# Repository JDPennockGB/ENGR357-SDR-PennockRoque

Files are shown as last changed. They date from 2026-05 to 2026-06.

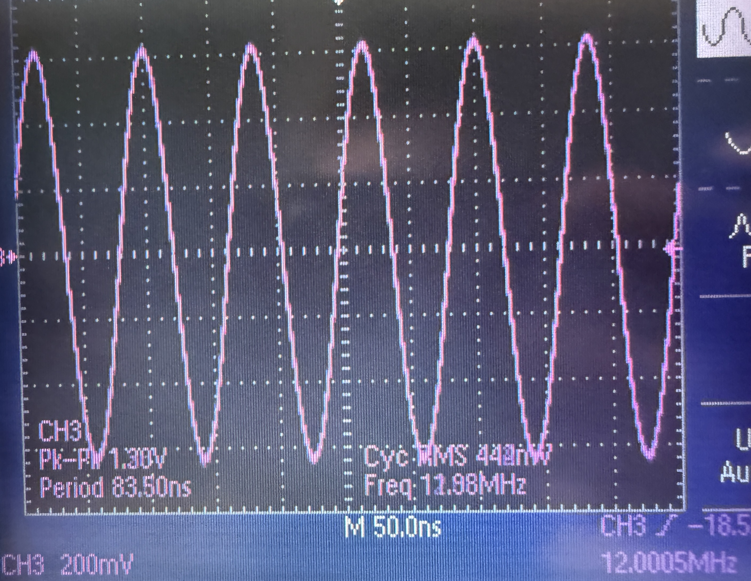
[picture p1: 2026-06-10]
Images/PicoClock.JPG

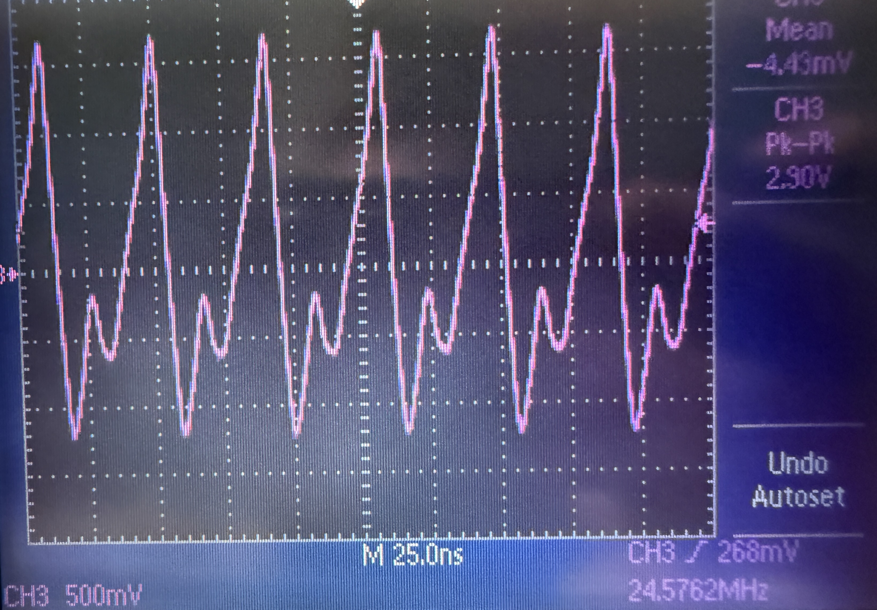
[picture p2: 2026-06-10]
Images/CmosClock.JPG

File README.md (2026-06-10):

# ENGR 357 Pico SDR Receiver

A custom-built, high-performance Software Defined Radio (SDR) receiver powered by the Raspberry Pi Pico (RP2040). This project combines a classic hardware Tayloe detector with modern digital signal processing, streaming 24-bit I/Q audio and CAT control over a single USB cable directly to PC-based SDR software like **Quisk**.

GitHub Link: https://github.com/JDPennockGB/ENGR357-SDR-PennockRoque 

---

## Overview

Traditional homebrew SDR receivers often rely on routing analog audio cables into a PC soundcard, which can introduce noise and ground loops. This project solves that by digitizing the baseband I/Q signals directly on the board using a dedicated 24-bit ADC, and utilizing the RP2040's hardware PIO and TinyUSB stack to act as a **Composite CDC-UAC1 USB Device**. 

When plugged into a computer, this radio appears simultaneously as:
1. **USB Audio Class 2.0 (UAC2) Input:** Streaming ultra-clean 24-bit stereo I/Q audio to the PC.
2. **USB CDC Serial Port:** Receiving standard CAT tuning commands from the SDR software.

## Key Features

ADD FEATURES

---

## Hardware
### Overview
* **MCU:** Raspberry Pi Pico (RP2040) utilizing PIO and DMA for zero-jitter data handling.
* **Clock Generator:** Si5351A providing precise LO generation and the 12.288 MHz Master Clock (MCLK) for the ADC.
* **Quadrature Generator:** SN74AC74 Johnson counter for exact 90-degree I/Q phase shifting.
* **Mixer (Tayloe Detector):** SN74CBT3253 Quadrature Sampling Detector.
* **Baseband Amplification:** OPA2350 high-speed, low-noise operational amplifiers.
* **Digitization:** PCM1808 24-bit Stereo I2S ADC.
* **User Interface:** * Newhaven 1x8 Character LCD (ST7066U / 3.3V)
  * Quadrature Rotary Encoder with push-button for VFO tuning
  * 4x SMD Push Buttons for menu/mode navigation (not currently implemented in software)

### Pinout Configuration
The following table outlines the physical connections between the Raspberry Pi Pico and your hardware components.

| Pin | Function | Connected | Implemented |
| :--- | :--- | :---: | :---: |
| **GPIO0** | BCK | ✅ | ❌ |
| **GPIO1** | WS | ✅ | ❌ |
| **GPIO2** | DOUT | ✅ | ❌ |
| **GPIO11** | SD | ✅ | ❌ |
| **GPIO3** | LCD_Bit0 | ✅ | ✅ |
| **GPIO4** | LCD_Bit1 | ✅ | ✅ |
| **GPIO5** | LCD_Bit2 | ✅ | ✅ |
| **GPIO6** | LCD_Bit3 | ✅ | ✅ |
| **GPIO7** | LCD_Bit4 | ✅ | ✅ |
| **GPIO8** | LCD_Bit5 | ✅ | ✅ |
| **GPIO9** | LCD_Bit6 | ✅ | ✅ |
| **GPIO10** | LCD_Bit7 | ✅ | ✅ |
| **GPIO12** | I2C Bus SDA | ✅ | ✅ |
| **GPIO13** | I2C Bus SCL | ✅ | ✅ |
| **GPIO14** | LCD_RegSel | ✅ | ✅ |
| **GPIO15** | LCD_Ena | ✅ | ✅ |
| **GPIO16** | Up_Btn | ✅ | ❌ |
| **GPIO17** | Left_Btn | ✅ | ❌ |
| **GPIO18** | Select_Btn | ✅ | ❌ |
| **GPIO19** | Right_Btn | ✅ | ❌ |
| **GPIO20** | Encoder_A | ✅ | ✅ |
| **GPIO21** | Encoder_B | ✅ | ✅ |
| **GPIO22** | Encoder_Button| ✅ | ❌ |
| **GPIO26** | ADC0 (I_OUT) | ❌ | ❌ |
| **GPIO27** | ADC1 (Q_OUT) | ❌ | ❌ |
| **AGND** | GND | ✅ | ✅ |
| **VBUS** | +5v Bus | ✅ | ✅ |
| **3v3** | +3.3v Bus | ✅ | ✅ |

---

## Software
### Overview
* **Framework:** C/C++ via the Raspberry Pi Pico SDK.
* **USB Stack:** TinyUSB configured for a unidirectional composite UAC1 Capture + CDC interface.
* **DSP Pipeline:** Custom PIO state machines reading I2S data, fed via DMA directly to USB buffers without bottlenecking the CPU.

### Function Reference

#### LCD Driver (`lcd_driver.c`)
Manages the 8-bit parallel interface for the ST7066U controller.

| Function | Description |
| :--- | :--- |
| `void lcd_init()` | [cite_start]Executes the power-on initialization routine, including the 3-step "Wake up" sequence required for the ST7066U controller to stabilize[cite: 259]. |
| `void lcd_command(uint8_t cmd)` | Sets the `RS` (Register Select) pin LOW for command mode, drives the 8-bit bus, and toggles the `E` (Enable) pin to latch data. |
| `void lcd_clear()` | [cite_start]Sends the `0x01` instruction to clear the display RAM and reset the cursor[cite: 178]. |
| `void lcd_print(const char* str)` | Sets `RS` HIGH for data mode, iterates through the string, and writes character bytes to the LCD data bus. |

#### Clock Synthesizer (`si5351.c`)
Interfaces with the Si5351 via I2C for frequency generation.

| Function | Description |
| :--- | :--- |
| `bool si5351_init(i2c_inst_t *i2c)` | [cite_start]Initializes I2C, verifies device status, and loads factory crystal load settings[cite: 172]. |
| `uint32_t si5351_set_frequency(...)` | Calculates PLL and MultiSynth divisors, programs the register blocks, resets the PLL to achieve frequency lock, and enables the output clock. |

#### Command & Control (`cdc_app.c` & `main.c`)
Handles communication and system state.

| Function | Description |
| :--- | :--- |
| `void cdc_task()` | Parses incoming serial data for Quisk-compatible commands (e.g., `FREQ`, `VER`, `XTAL`), enabling remote control of the SDR. |
| `static void process_command(const char *line)` | Dispatcher function that maps string commands (like `FREQ`) to specific hardware actions. |
| `void audio_task()` | Handles the audio buffer from the DMA/FIFO into the USB streaming interface. |
| `void encoder_callback(...)` | ISR that tracks encoder rotation to update the `current_hz` variable, which is then processed by the main loop. |

### Build Instructions
1. **Prerequisites**: Ensure the `Pico SDK` abd `TinyUSB` libraries are installed
2. **Setup**:
   ```bash
   cd /path/to/sdr-firmware
   rm -rf build && mkdir build && cd build

---

## Repository Structure

This repository contains the hardware design files, the C/C++ firmware, Python unit tests, and relevant research documentation.

ENGR-357-SDR/

├── Documents/              # Research notes, datasheets, and design requirements

├── KiCad Designs/          # PCB schematics, layout files, and BOMs

│   ├── v1 Switch Mixer/

│   ├── v2 Tayloe Detector/

│   └── v3 Tayloe Detector FINAL/

├── LT Spice Simulations/   # RF demodulator analysis and circuit models

│   ├── LTSpice project files/

│   └── Simulation Results/ # Images of simulation results

└── sdr-firmware/           # RP2040 Firmware (Pico SDK)

    ├── build/              # Compiled binaries and artifacts

    ├── PythonUnitTests/    # Verification and testing scripts

    └── main.c + drivers                # C firmware source files

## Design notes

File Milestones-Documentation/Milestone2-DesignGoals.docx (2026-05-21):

Milestone #2

SDR Design Goals and reasoning:

- Simplicity and reliability
- Low cost and accessibility of components
- Educational demonstrating both analog and digital signal processing

The goal of this project is to design and implement a software-assisted AM radio receiver capable of receiving and demodulating amplitude modulated (AM) signals in the standard broadcast band. The design combines analog front-end circuits with digital processing using a Raspberry Pico to create a flexible and cost-effective receiver.

Reasoning:

- AM modulation was chosen because it is simpler to implement and easier to demodulate compared to FM or SSB.
- A mixer + clock (local oscillator) is used to shift the signal to a lower frequency for easier processing.
- An ADC allows for conversion of analog signals into digital form, enabling software signal processing.

Specifications:

- Frequency range
  - 535–1705 kHz
- Modulation Type
  - AM (Amplitude Modulation)
- Minimum discernible signal
  - 10 µV
- User Interface
  - Rotary encoder
  - push buttons
  - LCD/OLED
- Processing Hardware
  - Raspberry Pi Pico RP2040 microcontroller
- Audio Output
  - Headphones or speaker
- Size/Weight
  - Handheld (Walkman size plus antenna)
- Power requirements
  - 5V via USB-C
- Software and computer requirements
  - Nice UI, easy to navigate and makes sense
- Special Features:
  - SD/.WAV recording
  - Storage – SD card or direct over USB
- Cost
  - $40 – $50 depending on components

System Architecture Overview

The receiver follows a Direct Conversion (Zero-IF) architecture. The radio frequency is mixed down to baseband (audio) using a high-speed analog switch driven by a programmable clock.

Signal Path & Sub-Circuits

A. The Front-End (Antenna & Filter)

- Antenna
- Protection: Back-to-back 1N4148 diodes to ground to prevent ESD damage.
- Pre-selector: A Passive Band-Pass Filter (BPF) designed for 500 kHz – 1.8 MHz. This prevents "images" from FM or Shortwave bands from entering the mixer.
- Buffer: A single-transistor JFET buffer (e.g., J310) to match the high-impedance antenna to the low-impedance detector.
- Transformer: Feeds into demodulator.

B. The Demodulator

- Switching IC: A high-speed analog demultiplexer.
- Operation: The switch rotates through 2 positions at the target frequency.

C. The Clock Engine (Digital Tuning)

- Clock Gen: Si5351A controlled via I2C by the Pi Pico.
- Frequency Logic: To listen to 1800 kHz, the Si5351 outputs 1800 kHz.

D. Post-Mixer Amplification (The "Bridge")

- Dual Op-Amp: NE5532 or TL072 configured as differential amplifiers.
- Biasing: Signal is biased for compatibility with the Pi Pico ADC.
- Filtering: Active Low-Pass Filter at 10 kHz to remove switching noise.

E. The Output Split

1. Digital Branch: Signal feed into Pico ADC (GP26/27).
2. Analog Branch: Signal passes through a 10µF DC-blocking capacitor -> Audio Potentiometer & Power Amplifier -> Speaker/3.5mm Jack.

3. Control & UI (The Pi Pico)

- Input: Rotary encoder for frequency selection.
- Display: I2C OLED to show the current frequency.
- Software: The Pico runs a loop that calculates the frequency for the Si5351 and can optionally perform an FFT on the ADC data to show a "spectrum" of the AM band.

Block Diagram:

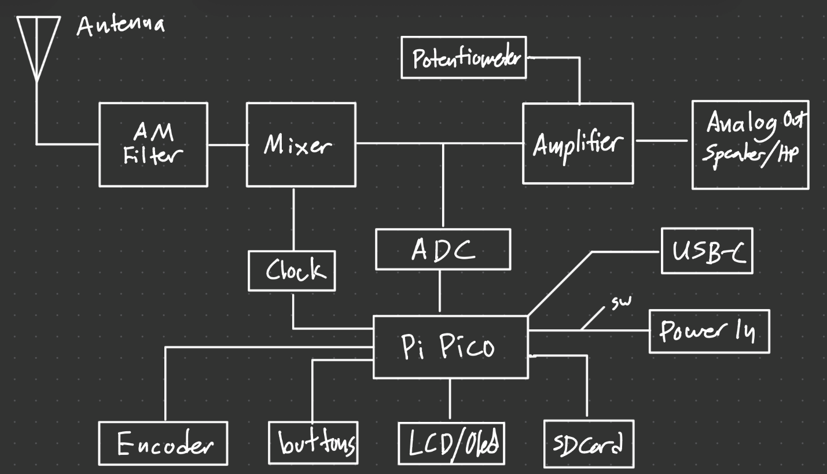
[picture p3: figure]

Explanation:

1. Antenna
  a. Receives electromagnetic AM signals from the air.
2. AM Filter
  a. Filters the incoming signal to isolate the desired frequency range and reduce interference from other signals.
3. Mixer + Clock (Local Oscillator)
  a. Local Oscillator acts like a signal generator, creating new signals. The mixer then combines the signal, lowering the frequency, making the radio process a lower frequency. Lower frequency allows for easier filtering
4. Signal Split Path
  a. One path goes to the ADC
  b. Another goes through an amplifier for audio output
5. ADC
  a. Convert the analog signal into digital samples.
6. Amplifier and Potentiometer
  a. Amplifies audio signal
  b. Potentiometer controls volume
7. Analog Output
  a. Outputs the recovered audio signal thorough speaker or headphones
8. Pi Pico
  a. Processes the sampled signal
  b. Controls display and storage
  c. Can demodulation extracting audio from AM signal
9. User Interface
  a. Encoder: tuning frequency
  b. Buttons: controls modes
  c. LCD/OLED: display frequency, status
10. Power Supply
  a. USB-C 5V
11. SD card
  a. Stores recorded signals or processed data.

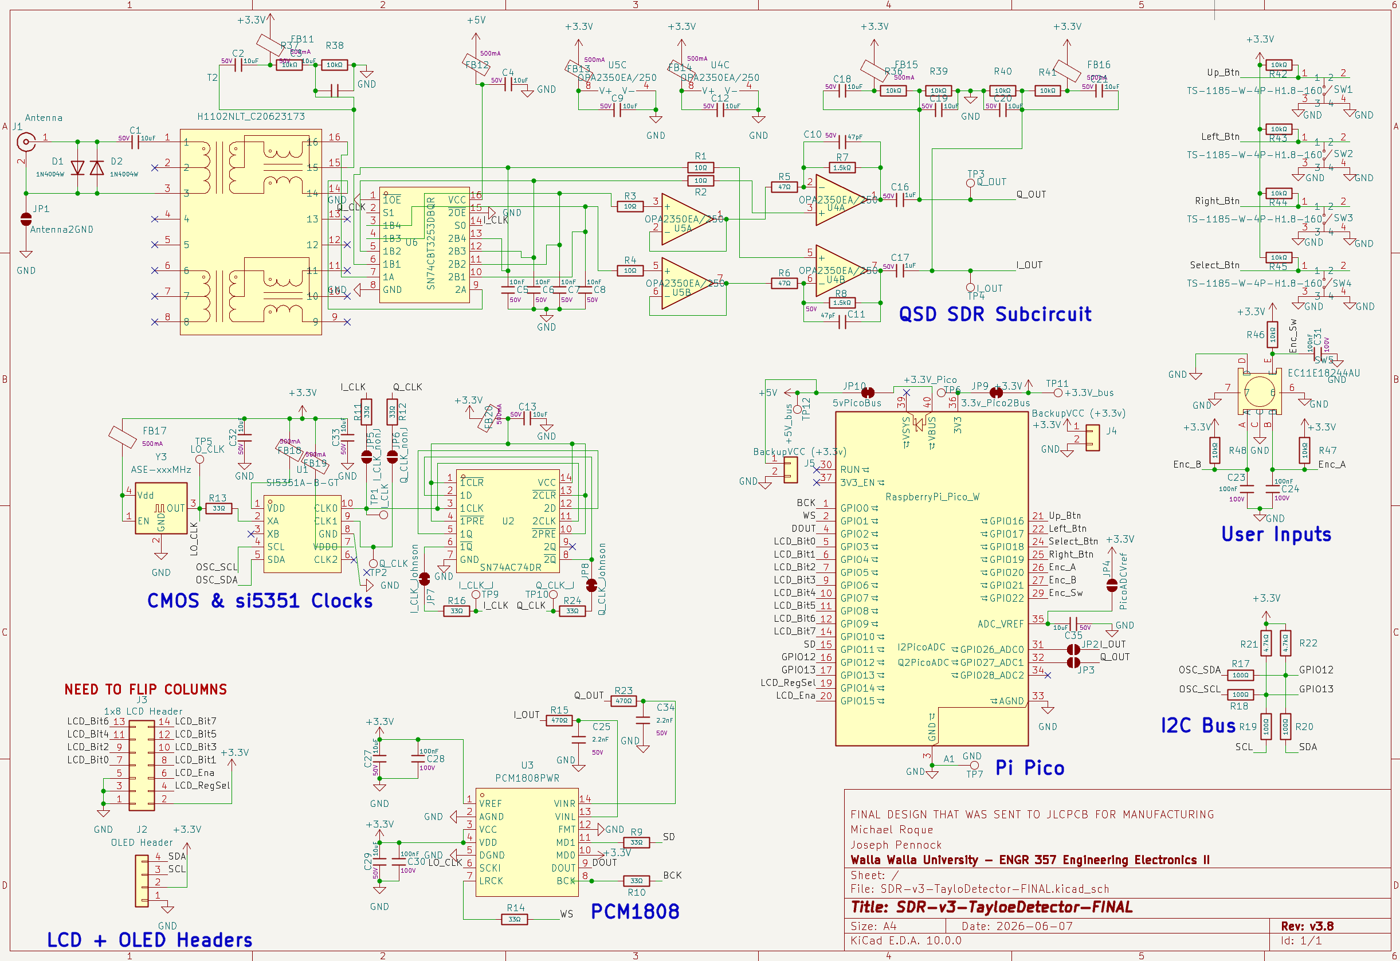
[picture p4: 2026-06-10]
Images/FullSchematic.png

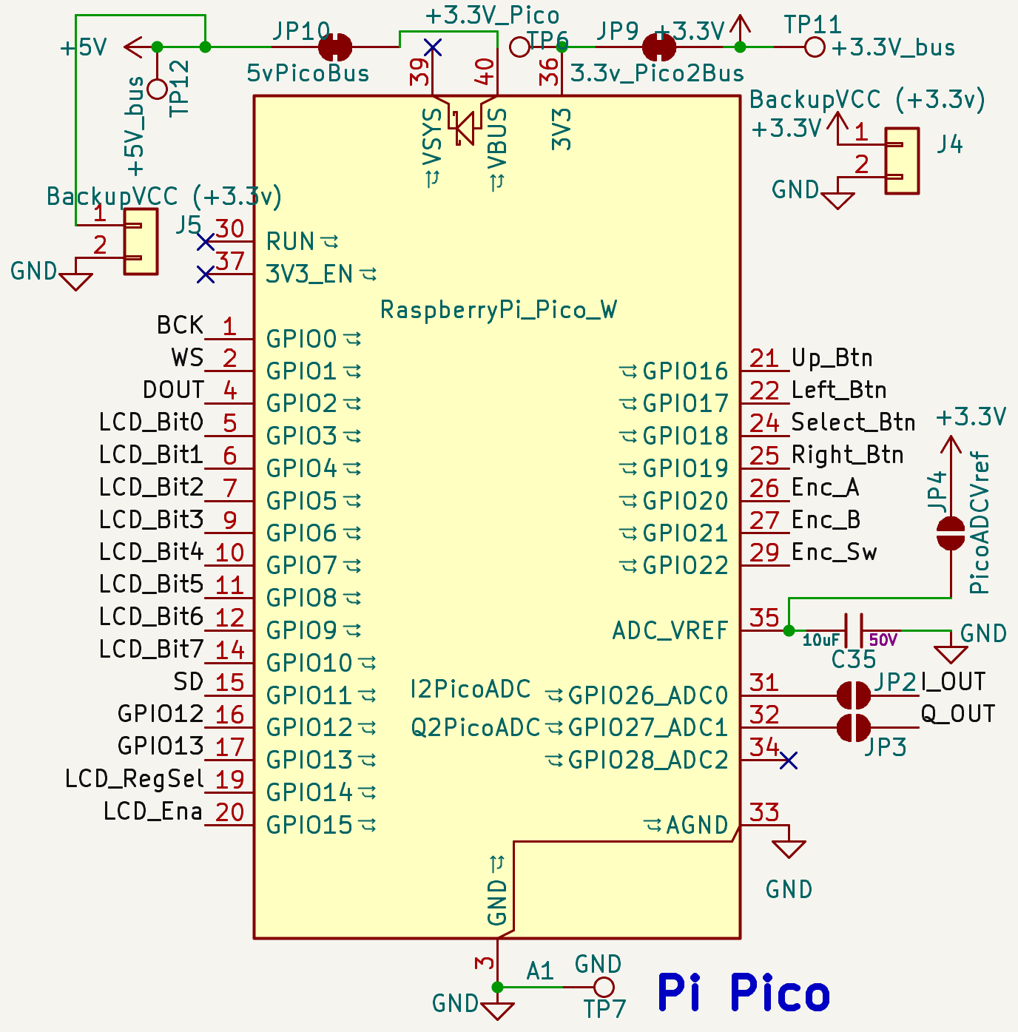
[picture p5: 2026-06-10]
Images/PicoCircuit.png

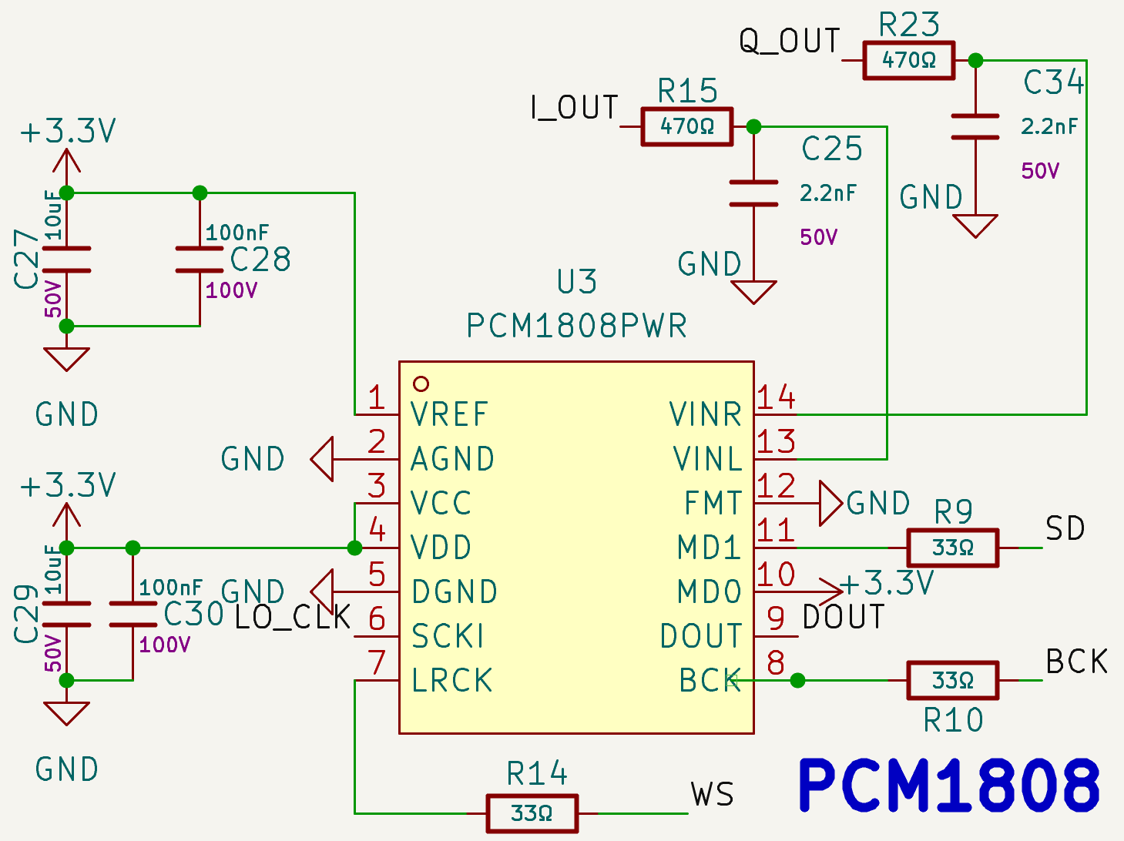
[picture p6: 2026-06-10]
Images/ADCcircuit.png

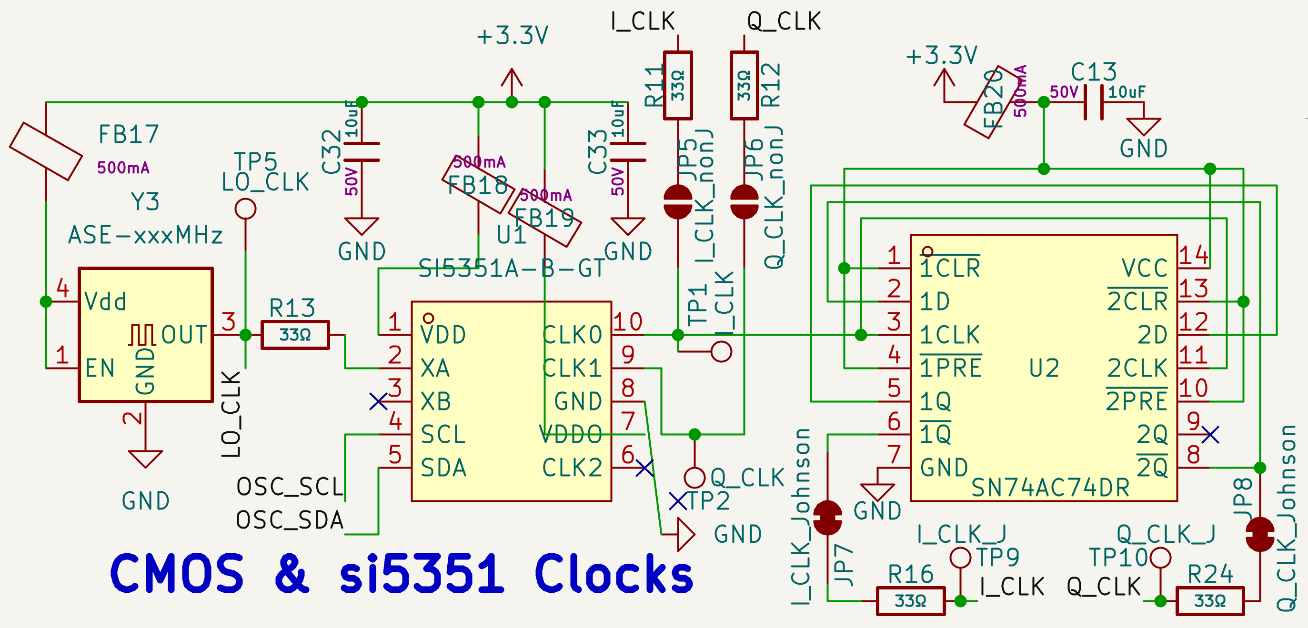
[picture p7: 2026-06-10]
Images/CMOSsi5351Circuit.png

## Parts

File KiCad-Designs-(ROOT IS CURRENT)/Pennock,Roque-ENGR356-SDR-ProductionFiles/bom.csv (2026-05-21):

Designator | Footprint | Quantity | Value | LCSC Part #
A1 | RaspberryPi_Pico_SMD | 1 | RaspberryPi_Pico | C7203002
C1, C12, C13, C18, C19, C2, C20, C21, C27, C29, C3, C32, C33, C35, C4, C9 | C_0805 | 16 | 10uF | C440198
C10, C11 | C_0805 | 2 | 47pF | C14857
C16, C17 | C_0805 | 2 | 1uF | C28323
C23, C24, C28, C30, C31 | C_0805 | 5 | 100nF | C28233
C25, C34 | C_0805 | 2 | 2.2nF | C28260
C5, C6, C7, C8 | C_0805 | 4 | 10nF | C1710
D1, D2 | D_SOD-123FL | 2 | 1N4004W | C18199087
FB11, FB12, FB13, FB14, FB15, FB16, FB17, FB18, FB19, FB20 | FB_0805 | 10 | ~ | C1017
J1 | BNC_Amphenol_B6252HB-NPP3G-50_Horizontal | 1 | Antenna
J2 | PinSocket_1x04_P2.54mm_Vertical | 1 | OLED Header
J3 | PinSocket_2x07_P2.54mm_Vertical | 1 | 1x8 LCD Header
J4, J5 | PinHeader_1x02_P2.54mm_Horizontal | 2 | BackupVCC (+3.3v)
R1, R2, R3, R4 | R_0805 | 4 | 10Ω | C17415
R10, R11, R12, R13, R14, R16, R24, R9 | R_0805 | 8 | 33Ω | C17634
R15, R23 | R_0805 | 2 | 470Ω | C17710
R17, R18, R19, R20 | R_0805 | 4 | 100Ω | C17408
R21, R22 | R_0805 | 2 | 4.7kΩ | C17673
R36, R37, R38, R39, R40, R41, R42, R43, R44, R45, R46, R47, R48 | R_0805 | 13 | 10kΩ | C17414
R5, R6 | R_0805 | 2 | 47Ω | C17714
R7, R8 | R_0805 | 2 | 1.5kΩ | C4310
SW1, SW2, SW3, SW4 | SW-SMD_4P-L3.5-W3.0-P1.50-LS4.7 | 4 | TS-1185-W-4P-H1.8-160 | C51927445
SW5 | SW-TH_EC11XXXXXXXX | 1 | EC11E18244AU | C202365
T2 | XFMR-SMD_H1102NLT | 1 | H1102NLT_C20623173 | C20623173
TP1 | TestPoint_THTPad_D2.0mm_Drill1.0mm | 1 | I_CLK
TP10 | TestPoint_THTPad_D2.0mm_Drill1.0mm | 1 | Q_CLK_J
TP11 | TestPoint_THTPad_D2.0mm_Drill1.0mm | 1 | +3.3V_bus
TP12 | TestPoint_THTPad_D2.0mm_Drill1.0mm | 1 | +5V_bus
TP2 | TestPoint_THTPad_D2.0mm_Drill1.0mm | 1 | Q_CLK
TP3 | TestPoint_THTPad_D2.0mm_Drill1.0mm | 1 | Q_OUT
TP4 | TestPoint_THTPad_D2.0mm_Drill1.0mm | 1 | I_OUT
TP5 | TestPoint_THTPad_D2.0mm_Drill1.0mm | 1 | LO_CLK
TP6 | TestPoint_THTPad_D2.0mm_Drill1.0mm | 1 | +3.3V_Pico
TP7 | TestPoint_THTPad_D2.0mm_Drill1.0mm | 1 | GND
TP9 | TestPoint_THTPad_D2.0mm_Drill1.0mm | 1 | I_CLK_J
U1 | MSOP-10_L3.0-W3.0-P0.50-LS5.0-BL | 1 | SI5351A-B-GT | C529366
U2 | SOIC-14_L8.7-W3.9-P1.27-LS6.0-BL | 1 | SN74AC74DR | C352945
U3 | TSSOP-14_L5.0-W4.4-P0.65-LS6.4-BL | 1 | PCM1808PWR | C55513
U4, U5 | VSSOP-8_L3.0-W3.0-P0.65-LS5.0-BL | 2 | OPA2350EA/250 | C115876
U6 | SSOP-16_L4.9-W3.9-P0.64-LS6.0-BL | 1 | SN74CBT3253DBQR | C2674552
Y3 | Oscillator_SMD_Abracon_ASE-4Pin_3.2x2.5mm | 1 | ASE-xxxMHz | C52204801

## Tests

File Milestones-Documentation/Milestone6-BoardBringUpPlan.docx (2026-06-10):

SDR Board Bring Up and Testing Plan

Stage 1: Power Off Check

Verify there are no manufacturing defects

- Visual Inspection: Use magnification to inspect for solder bridges, especially on the PCM1808, 74CBT3253, Si5351, and Pico headers.

Result: PASS

- Continuity Test: Verify there is no short between the 3.3V rail and GND.

Result: PASS, >15k ohm for 5v and >4kohm for 3.3v

- Bias Check: Confirm the 1.65V virtual ground is not shorted to either power or ground. Result: PASS

Stage 2: Power Rail Verification

Verify all supply rails before running the actual circuits or software.

- Initial Power-Up: Apply power using a current-limited bench supply set to approximately 100mA

Result: PASS

- Measurements: Verify the 3.3V rail at the Pico, Si5351, PCM1808, and op amps.

Result: PASS

- Reference Check: Confirm the bias is stable around 1.65V

Result: PASS

Stage 3: Pi Pico & Display

Verify the microcontroller and display operate correctly.

- Software Needed: Simple Pico firmware to initialize the LCD/OLED and display text.

Result: PASS

- Tests: Confirm the display initializes and text appears correctly.

Result: PASS

- Contrast Check: Verify LCD contrast pin Vout is properly grounded.

Result: PASS

Stage 4: I2C Bus Verification

- Software Needed: Pico I2C scanner firmware.

Result: DONE

- Tests: Detect expected device addresses on the bus.

Result: PASS

- Signal Check: Use oscilloscope to confirm SDA and SCL pull-ups and clean transitions.

Result: PASS

Stage 5: Clock Generation & Tayloe Detector

This stage verifies the SDR clocking and quadrature switching system.

- Software Needed: Pico firmware to configure the Si5351 over I2C.

Result: PASS

- Clock Verification: Measure Si5351 outputs and confirm the 74AC74 generates quadrature I_CKL and Q_CLK signals.

Result: PASS

- Expected: Expected: Two stable square waves with one signal shifted 90 degree relative to the other.

Result: PASS

Stage 6: Analog Signal Chain Verification

Before testing RF reception, verify the analog amplification and filtering stages.

- Quiescent Check: Measure op amp outputs and confirm DC bias is approximately 1.65V.

Result: PASS

- Signal Injection: Apply a small 1kHz sine wave from a function generator to the analog input and observe the waveform at each amplifier and filter stage using an oscilloscope.

Result: PASS

- Expected Result: The signal should propagate cleanly through the analog chain with the expected gain and filtering characteristics.

Result: PASS

- Filter Verification: Measure the signal before and after the filter stage to confirm the signal passes through correctly and is modified according to the expected filter response.

Result: PASS

Stage 7: PCM1808 Digital Audio Verification

Verify the ADC and I2S interface operation.

- Software Needed: Pico firmware to capture I2S audio data.

Result: FAIL

- Measurements Verification: Confirm presence of BCK, LRCK, SCKI, and DOUT signals with oscilloscope.

Result: PASS

Stage 8: Full SDR System Test

After verifying all subsystems independently, perform end-to-end SDR testing.

- Connect an antenna or RF signal generator.

Result: PASS

- Tune to a known RF signal.

Result: PASS

- Verify valid I/Q outputs and observable received signals.

Result: PASS

- Confirm the SDR can successfully process and display received data

Result: FAIL

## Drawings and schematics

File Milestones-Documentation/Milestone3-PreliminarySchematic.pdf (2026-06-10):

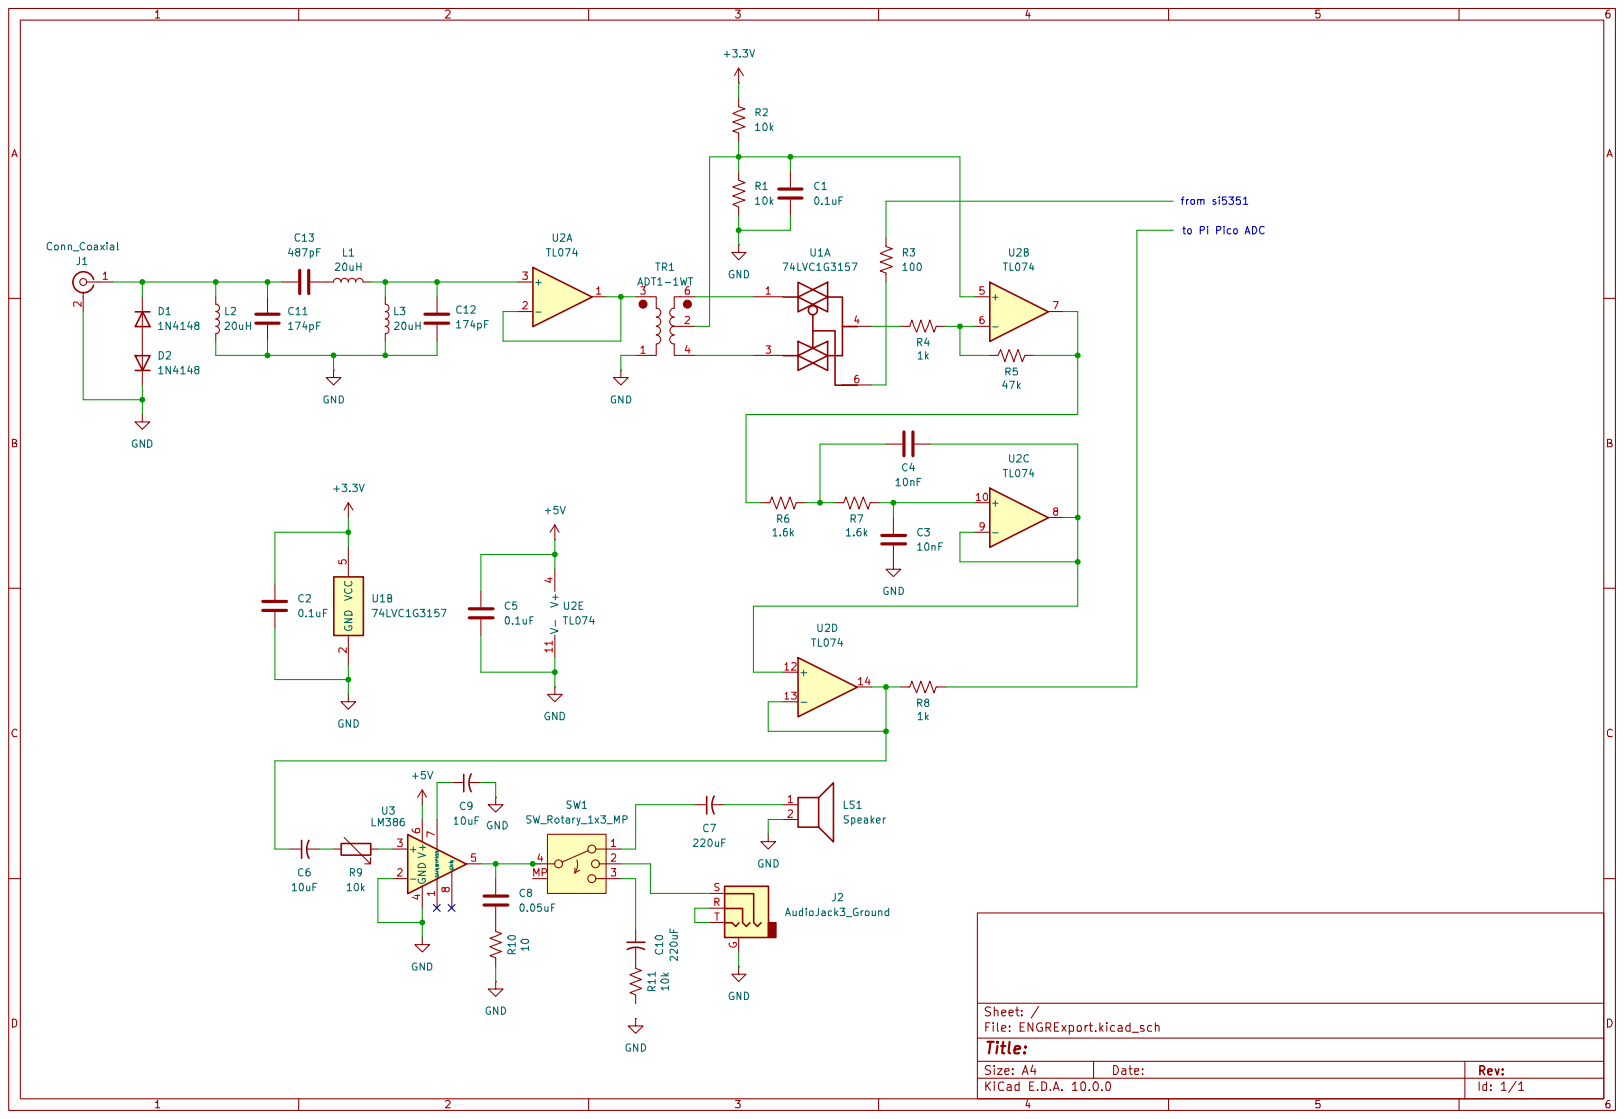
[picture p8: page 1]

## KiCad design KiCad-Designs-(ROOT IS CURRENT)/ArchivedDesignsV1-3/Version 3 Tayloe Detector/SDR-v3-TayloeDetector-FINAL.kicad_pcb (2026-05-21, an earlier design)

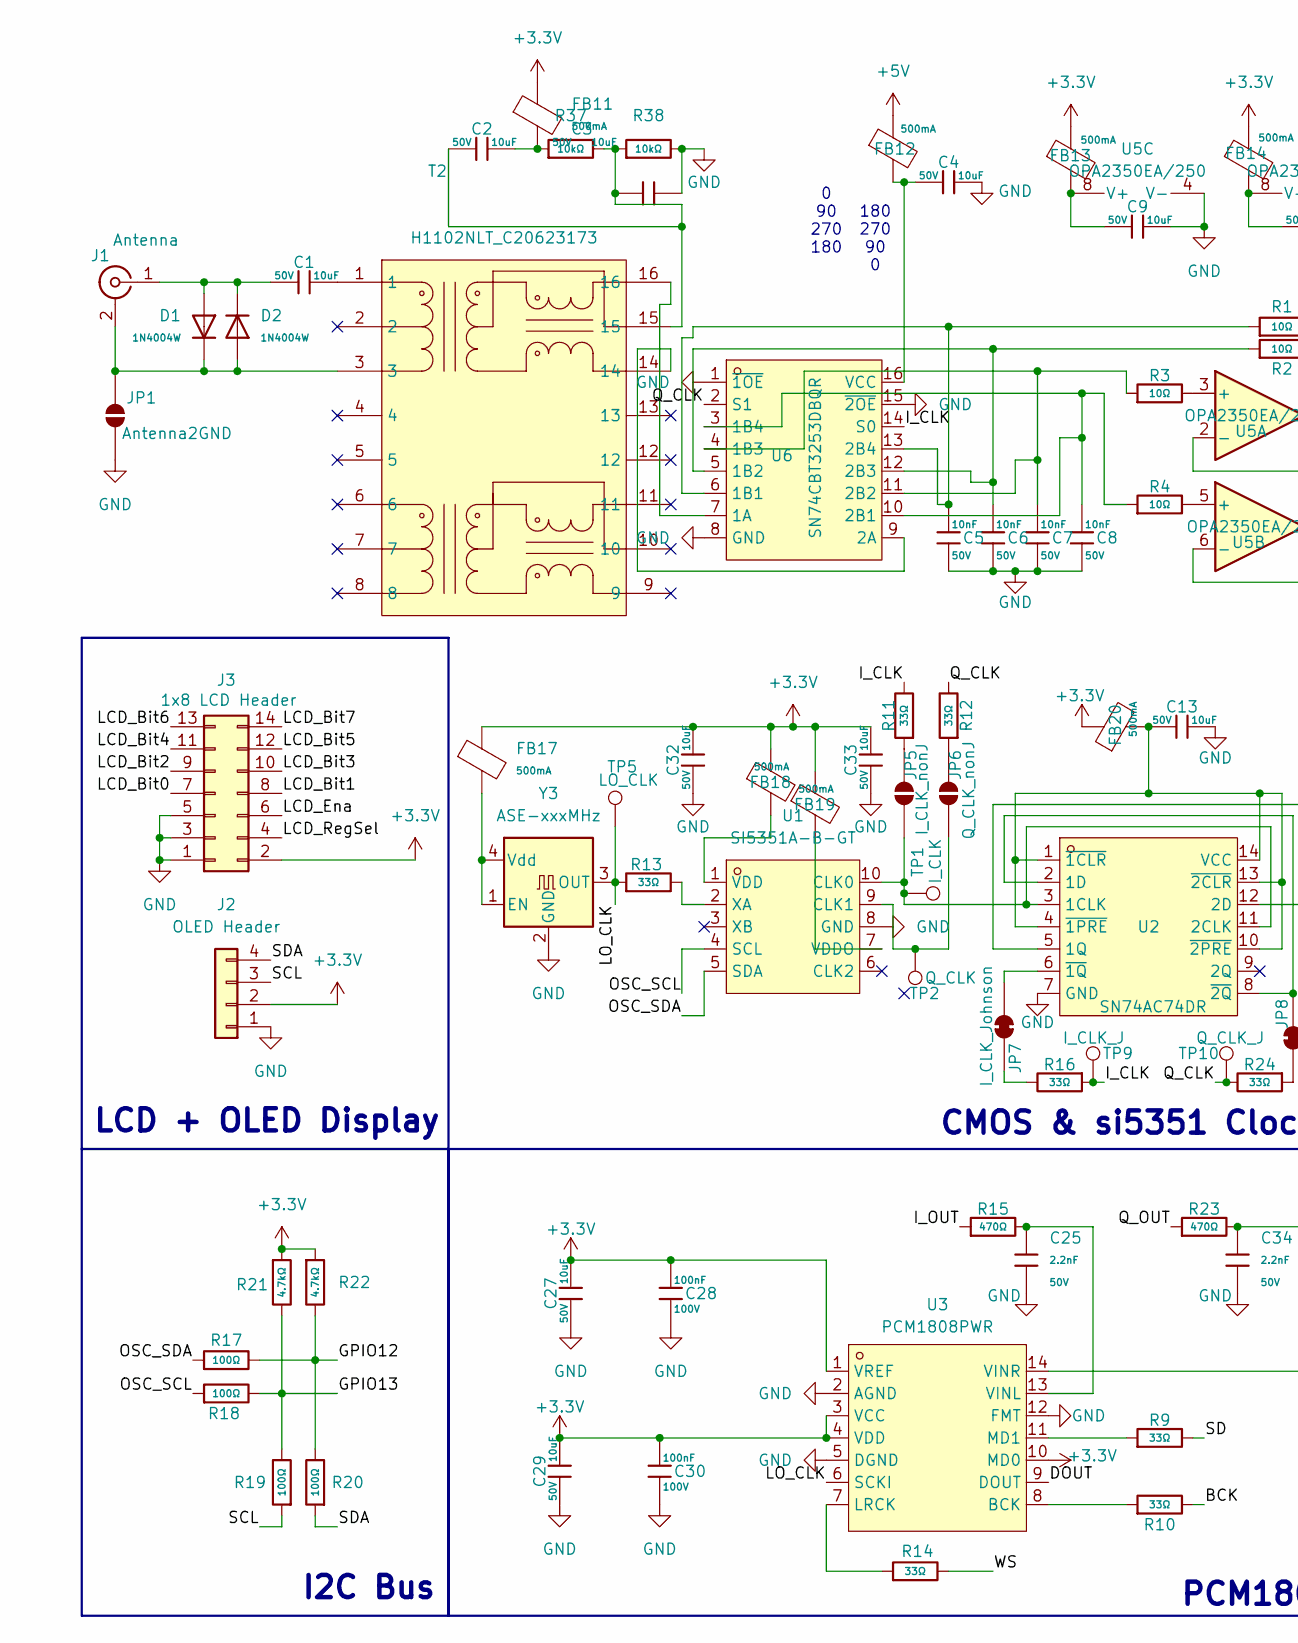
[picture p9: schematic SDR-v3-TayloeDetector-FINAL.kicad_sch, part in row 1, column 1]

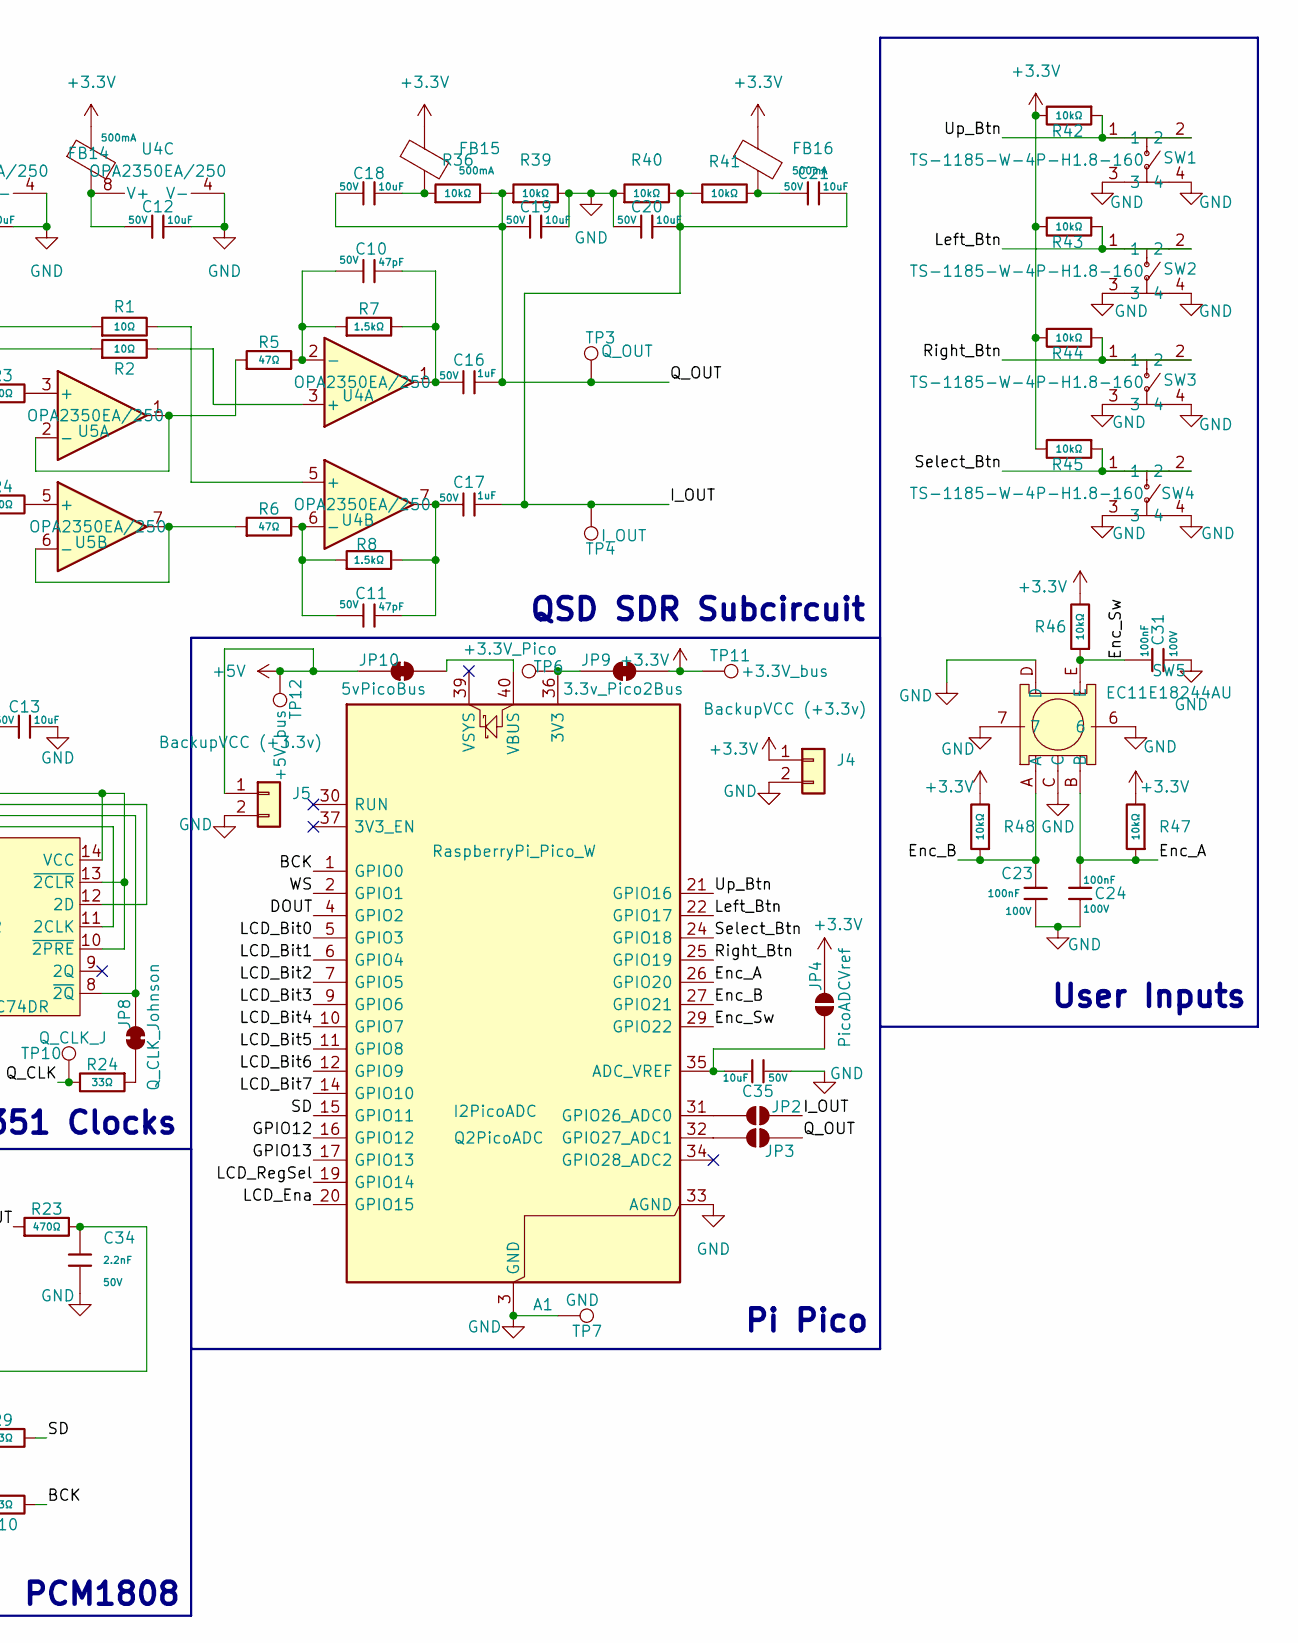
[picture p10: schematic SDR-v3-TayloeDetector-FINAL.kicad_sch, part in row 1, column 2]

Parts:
A1: RaspberryPi_Pico_W; RaspberryPi_Pico_SMD
C1, C2, C3, C4, C9, C12, C13, C18, C19, C20, C21, C27, C29, C32, C33, C35: 10uF; C_0805; Voltage Rated 50V; Tolerance ±10%; Part GRM21BR61H106KE43L; LCSC C440198
C5, C6, C7, C8: 10nF; C_0805; Voltage Rated 50V; Tolerance ±10%; Part CL21B103KBANNNC; LCSC C1710
C10, C11: 47pF; C_0805; Voltage Rated 50V; Tolerance ±5%; Part CL21C470JBANNNC; LCSC C14857
C16, C17: 1uF; C_0805; Voltage Rated 50V; Tolerance ±10%; Part CL21B105KBFNNNE; LCSC C28323
C23, C24, C28, C30, C31: 100nF; C_0805; Voltage Rated 100V; Tolerance ±10%; Part CL21B104KCFNNNE; LCSC C28233
C25, C34: 2.2nF; C_0805; Voltage Rated 50V; Tolerance ±5%; Part CL21C222JBFNNNE; LCSC C28260
D1, D2: 1N4004W; D_SOD-123FL; Forward Voltage (Vf@If) 1V@1.0A; Reverse Voltage (Vr) 400V; Part 1N4004W; LCSC C18199087
FB11, FB12, FB13, FB14, FB15, FB16, FB17, FB18, FB19, FB20: FB_0805; Current Rating 500mA; Tolerance ±25%; Part GZ2012D601TF; LCSC C1017
J1: Antenna; BNC_Amphenol_B6252HB-NPP3G-50_Horizontal
J2: OLED Header; PinSocket_1x04_P2.54mm_Vertical
J3: 1x8 LCD Header; PinSocket_2x07_P2.54mm_Vertical
J4, J5: BackupVCC (+3.3v); PinHeader_1x02_P2.54mm_Horizontal
JP1: Antenna2GND; SolderJumper-2_P1.3mm_Open_RoundedPad1.0x1.5mm
JP2: I2PicoADC; SolderJumper-2_P1.3mm_Open_RoundedPad1.0x1.5mm
JP3: Q2PicoADC; SolderJumper-2_P1.3mm_Open_RoundedPad1.0x1.5mm
JP4: PicoADCVref; SolderJumper-2_P1.3mm_Open_RoundedPad1.0x1.5mm
JP5: I_CLK_nonJ; SolderJumper-2_P1.3mm_Open_RoundedPad1.0x1.5mm
JP6: Q_CLK_nonJ; SolderJumper-2_P1.3mm_Open_RoundedPad1.0x1.5mm
JP7: I_CLK_Johnson; SolderJumper-2_P1.3mm_Bridged_RoundedPad1.0x1.5mm
JP8: Q_CLK_Johnson; SolderJumper-2_P1.3mm_Bridged_RoundedPad1.0x1.5mm
JP9: 3.3v_Pico2Bus; SolderJumper-2_P1.3mm_Bridged_RoundedPad1.0x1.5mm
JP10: 5vPicoBus; SolderJumper-2_P1.3mm_Bridged_RoundedPad1.0x1.5mm
R1, R2, R3, R4: 10Ω; R_0805; Overload Voltage (Max) 150V; Tolerance ±1%; Part 0805W8F100JT5E; LCSC C17415
R5, R6: 47Ω; R_0805; Overload Voltage (Max) 150V; Tolerance ±1%; Part 0805W8F470JT5E; LCSC C17714
R7, R8: 1.5kΩ; R_0805; Overload Voltage (Max) 150V; Tolerance ±1%; Part 0805W8F1501T5E; LCSC C4310
R9, R10, R11, R12, R13, R14, R16, R24: 33Ω; R_0805; Overload Voltage (Max) 150V; Tolerance ±1%; Part 0805W8F330JT5E; LCSC C17634
R15, R23: 470Ω; R_0805; Overload Voltage (Max) 150V; Tolerance ±1%; Part 0805W8F4700T5E; LCSC C17710
R17, R18, R19, R20: 100Ω; R_0805; Overload Voltage (Max) 150V; Tolerance ±1%; Part 0805W8F1000T5E; LCSC C17408
R21, R22: 4.7kΩ; R_0805; Overload Voltage (Max) 150V; Tolerance ±1%; Part 0805W8F4701T5E; LCSC C17673
R36, R37, R38, R39, R40, R41, R42, R43, R44, R45, R46, R47, R48: 10kΩ; R_0805; Overload Voltage (Max) 150V; Tolerance ±1%; Part 0805W8F1002T5E; LCSC C17414
SW1, SW2, SW3, SW4: TS-1185-W-4P-H1.8-160; SW-SMD_4P-L3.5-W3.0-P1.50-LS4.7; MPN TS-1185-W-4P-H1.8-160; LCSC Part C51927445
SW5: EC11E18244AU; SW-TH_EC11XXXXXXXX; MPN EC11E18244AU; LCSC Part C202365
T2: H1102NLT_C20623173; XFMR-SMD_H1102NLT; MPN H1102NLT; LCSC Part C20623173
TP1: I_CLK; TestPoint_THTPad_D2.0mm_Drill1.0mm
TP2: Q_CLK; TestPoint_THTPad_D2.0mm_Drill1.0mm
TP3: Q_OUT; TestPoint_THTPad_D2.0mm_Drill1.0mm
TP4: I_OUT; TestPoint_THTPad_D2.0mm_Drill1.0mm
TP5: LO_CLK; TestPoint_THTPad_D2.0mm_Drill1.0mm
TP6: +3.3V_Pico; TestPoint_THTPad_D2.0mm_Drill1.0mm
TP7: GND; TestPoint_THTPad_D2.0mm_Drill1.0mm
TP9: I_CLK_J; TestPoint_THTPad_D2.0mm_Drill1.0mm
TP10: Q_CLK_J; TestPoint_THTPad_D2.0mm_Drill1.0mm
TP11: +3.3V_bus; TestPoint_THTPad_D2.0mm_Drill1.0mm
TP12: +5V_bus; TestPoint_THTPad_D2.0mm_Drill1.0mm
U1: SI5351A-B-GT; MSOP-10_L3.0-W3.0-P0.50-LS5.0-BL; MPN SI5351A-B-GT; LCSC Part C529366
U2: SN74AC74DR; SOIC-14_L8.7-W3.9-P1.27-LS6.0-BL; MPN SN74AC74DR; LCSC Part C352945
U3: PCM1808PWR; TSSOP-14_L5.0-W4.4-P0.65-LS6.4-BL; MPN PCM1808PWR; LCSC Part C55513
U4, U5: OPA2350EA/250; VSSOP-8_L3.0-W3.0-P0.65-LS5.0-BL
U6: SN74CBT3253DBQR; SSOP-16_L4.9-W3.9-P0.64-LS6.0-BL; MPN SN74CBT3253DBQR; LCSC Part C2674552
Y3: ASE-xxxMHz; Oscillator_SMD_Abracon_ASE-4Pin_3.2x2.5mm

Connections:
+3.3V: C27.2, C28.1, C29.2, C30.1, C32.2, C33.2, FB11.1, FB13.1, FB14.1, FB15.1, FB16.1, FB17.1, FB18.1, FB19.1, FB20.1, J2.2, J3.2, J4.1, JP4.1 (A), JP9.1 (A), R21.1, R22.1, R42.2, R43.2, R44.2, R45.2, R46.2, R47.2, R48.2, TP11.1 (1_1), U3.1 (VREF), U3.3 (VCC), U3.4 (VDD), U3.10 (MD0)
+5V: FB12.1, J5.1, JP10.2 (B), TP12.1 (1_1)
/BCK: A1.1 (GPIO0), R10.2
/DOUT: A1.4 (GPIO2), U3.9 (DOUT)
/Enc_A: A1.26 (GPIO20), C24.1, R47.1, SW5.B
/Enc_B: A1.27 (GPIO21), C23.1, R48.1, SW5.A
/Enc_Sw: A1.29 (GPIO22), C31.1, R46.1, SW5.E
/GPIO12: A1.16 (GPIO12), R17.2, R20.2, R22.2
/GPIO13: A1.17 (GPIO13), R18.2, R19.2, R21.2
/I_CLK: R11.2, R16.1, TP9.1 (1_1), U6.14 (S0)
/I_OUT: C17.2, C20.2, C21.2, JP2.1 (A), R15.1, R40.2, R41.1, TP4.1 (1_1)
/LCD_Bit0: A1.5 (GPIO3), J3.7
/LCD_Bit1: A1.6 (GPIO4), J3.8
/LCD_Bit2: A1.7 (GPIO5), J3.9
/LCD_Bit3: A1.9 (GPIO6), J3.10
/LCD_Bit4: A1.10 (GPIO7), J3.11
/LCD_Bit5: A1.11 (GPIO8), J3.12
/LCD_Bit6: A1.12 (GPIO9), J3.13
/LCD_Bit7: A1.14 (GPIO10), J3.14
/LCD_Ena: A1.20 (GPIO15), J3.6
/LCD_RegSel: A1.19 (GPIO14), J3.4
/LO_CLK: R13.1, TP5.1 (1_1), U3.6 (SCKI), Y3.3 (OUT)
/Left_Btn: A1.22 (GPIO17), R43.1, SW2.1, SW2.2
/OSC_SCL: R18.1, U1.4 (SCL)
/OSC_SDA: R17.1, U1.5 (SDA)
/Q_CLK: R12.2, R24.2, TP10.1 (1_1), U6.2 (S1)
/Q_OUT: C16.2, C18.1, C19.1, JP3.1 (A), R23.1, R36.2, R39.1, TP3.1 (1_1)
/Right_Btn: A1.25 (GPIO19), R44.1, SW3.1, SW3.2
/SCL: J2.3, R19.1
/SD: A1.15 (GPIO11), R9.2
/SDA: J2.4, R20.1
/Select_Btn: A1.24 (GPIO18), R45.1, SW4.1, SW4.2
/Up_Btn: A1.21 (GPIO16), R42.1, SW1.1, SW1.2
/WS: A1.2 (GPIO1), R14.2
GND: A1.3 (GND), A1.8 (GND), A1.13 (GND), A1.18 (GND), A1.23 (GND), A1.28 (GND), A1.33 (AGND), A1.38 (GND), C3.2, C4.2, C5.2, C6.2, C7.2, C8.2, C9.2, C12.2, C13.2, C19.2, C20.1, C23.2, C24.2, C25.2, C27.1, C28.2, C29.1, C30.2, C31.2, C32.1, C33.1, C34.2, C35.1, J2.1, J3.1, J3.3, J3.5, J4.2, J5.2, JP1.2 (B), R38.2, R39.2, R40.1, SW1.3, SW1.4, SW2.3, SW2.4, SW3.3, SW3.4, SW4.3, SW4.4, SW5.6, SW5.7, SW5.C, SW5.D, TP7.1 (1_1), U1.8 (GND), U2.7 (GND), U3.2 (AGND), U3.5 (DGND), U3.12 (FMT), U4.4 (V-), U5.4 (V-), U6.1 (~1OE), U6.8 (GND), U6.15 (~2OE), Y3.2 (GND)
unnamed: A1.36 (3V3), JP9.2 (B), TP6.1 (1_1)
unnamed: A1.35 (ADC_VREF), C35.2, JP4.2 (B)
unnamed: A1.31 (GPIO26_ADC0), JP2.2 (B)
unnamed: A1.32 (GPIO27_ADC1), JP3.2 (B)
unnamed: A1.40 (VBUS), JP10.1 (A)
unnamed: C1.2, T2.1
unnamed: C2.1, C3.1, R37.2, R38.1, T2.15
unnamed: C2.2, FB11.2, R37.1
unnamed: C10.2, C16.1, R7.2, U4.1
unnamed: C11.2, C17.1, R8.2, U4.7
unnamed: C18.2, FB15.2, R36.1
unnamed: C21.1, FB16.2, R41.2
unnamed: D1.1, D2.2, J1.2 (Ext), JP1.1 (A), T2.3
unnamed: C1.1, D1.2, D2.1, J1.1 (In)
unnamed: JP5.1 (A), R11.1
unnamed: JP5.2 (B), TP1.1 (1_1), U1.10 (CLK0), U2.3 (1CLK), U2.11 (2CLK)
unnamed: JP6.1 (A), R12.1
unnamed: JP6.2 (B), TP2.1 (1_1), U1.9 (CLK1)
unnamed: JP7.1 (A), R16.2
unnamed: JP7.2 (B), U2.6 (~1Q)
unnamed: JP8.1 (A), R24.1
unnamed: JP8.2 (B), U2.2 (1D), U2.8 (~2Q)
unnamed: FB18.2, U1.1 (VDD)
unnamed: FB19.2, U1.7 (VDDO)
unnamed: R13.2, U1.2 (XA)
unnamed: U2.5 (1Q), U2.12 (2D)
unnamed: C13.1, FB20.2, U2.1 (~1CLR), U2.4 (~1PRE), U2.10 (~2PRE), U2.13 (~2CLR), U2.14 (VCC)
unnamed: R10.1, U3.8 (BCK)
unnamed: R14.1, U3.7 (LRCK)
unnamed: R9.1, U3.11 (MD1)
unnamed: C25.1, R15.2, U3.13 (VINL)
unnamed: C34.1, R23.2, U3.14 (VINR)
unnamed: R2.2, U4.3 (+)
unnamed: C10.1, R5.2, R7.1, U4.2 (-)
unnamed: R1.2, U4.5 (+)
unnamed: C11.1, R6.2, R8.1, U4.6 (-)
unnamed: C12.1, FB14.2, U4.8 (V+)
unnamed: R3.2, U5.3 (+)
unnamed: R5.1, U5.1, U5.2 (-)
unnamed: R4.2, U5.5 (+)
unnamed: R6.1, U5.6 (-), U5.7
unnamed: C9.1, FB13.2, U5.8 (V+)
unnamed: T2.16, U6.7 (1A)
unnamed: C5.1, R1.1, U6.6 (1B1), U6.13 (2B4)
unnamed: C6.1, R2.1, U6.5 (1B2), U6.12 (2B3)
unnamed: C7.1, R3.1, U6.4 (1B3), U6.11 (2B2)
unnamed: C8.1, R4.1, U6.3 (1B4), U6.10 (2B1)
unnamed: T2.14, U6.9 (2A)
unnamed: C4.1, FB12.2, U6.16 (VCC)
unnamed: FB17.2, Y3.1 (EN), Y3.4 (Vdd)

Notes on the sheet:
CMOS & si5351 Clocks
I2C Bus
180 270 90 0
PCM1808
User Inputs
LCD + OLED Display
0 90 270 180
Pi Pico
QSD SDR Subcircuit

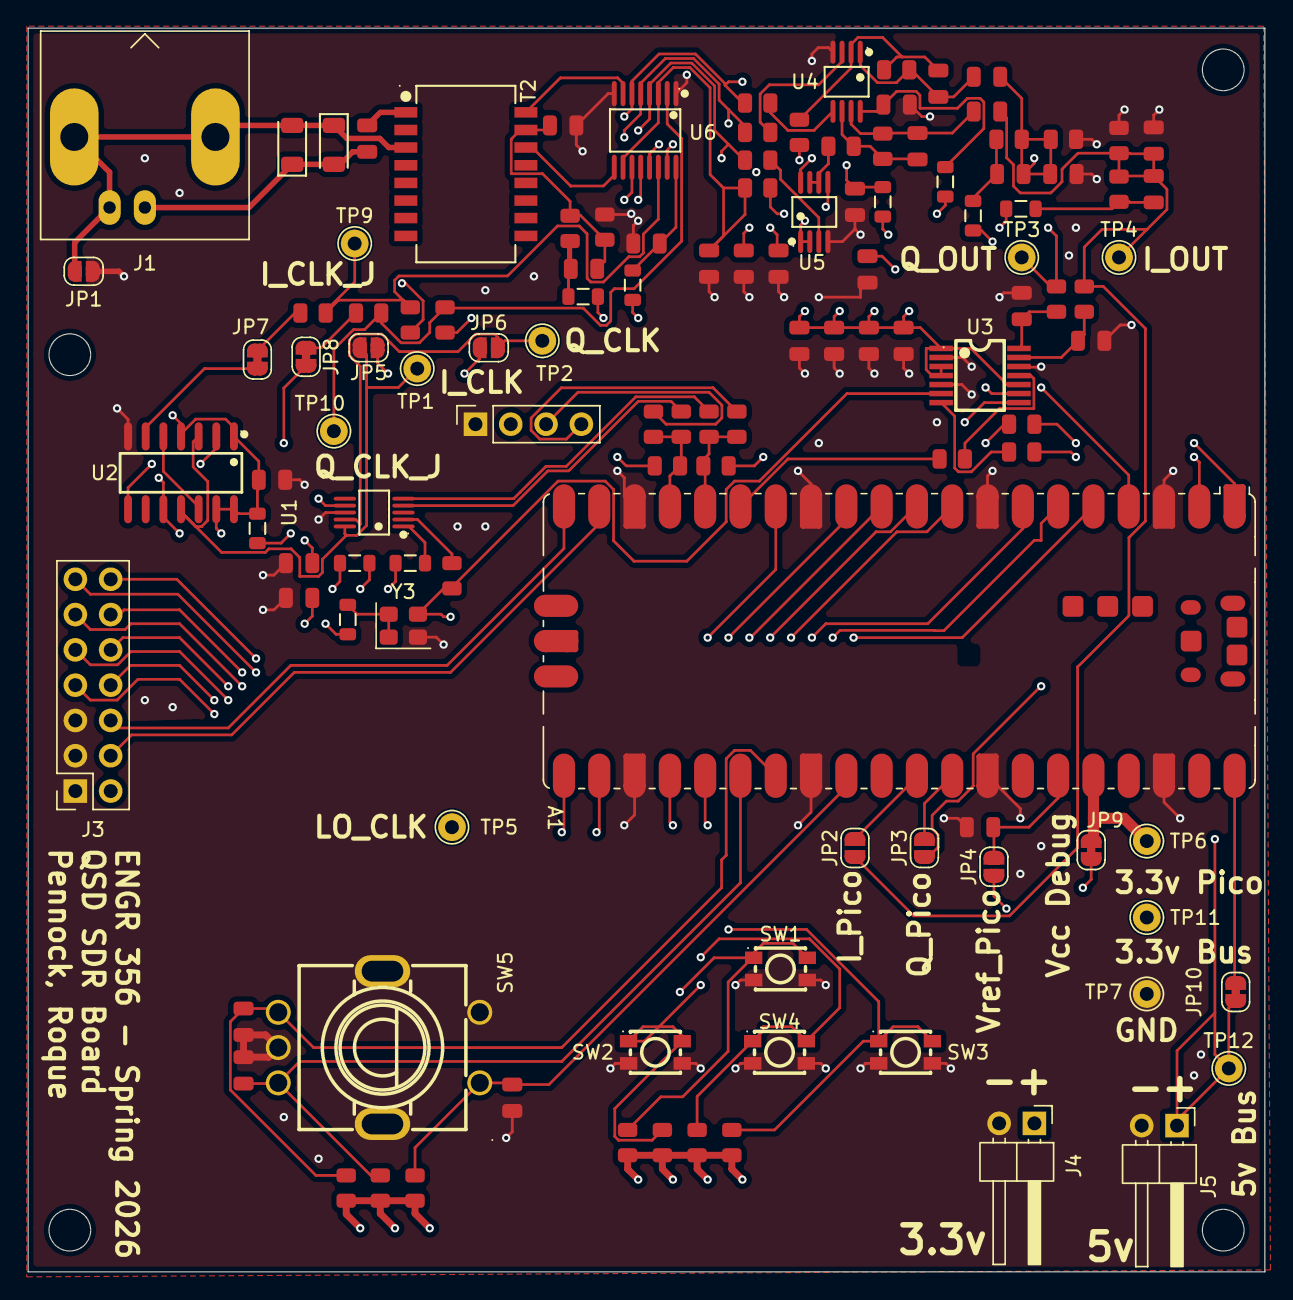
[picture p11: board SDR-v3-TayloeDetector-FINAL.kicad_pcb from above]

Board: 4 copper layers, 89.0 x 89.5 mm, 120 parts (0 on the bottom side), 85 nets.

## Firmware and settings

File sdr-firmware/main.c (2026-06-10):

/**
 * SDR Controller - Main Firmware
 * Pinout Configured: DOUT=GPIO2, SD=GPIO11, LCD=GPIO3-10,14,15
 */

  // fixed verson for new drivers

#include <stdio.h>
#include <string.h>
#include <stdint.h>
#include "pico/stdlib.h"
#include "pico/multicore.h"
#include "hardware/pio.h"
#include "hardware/dma.h"
#include "hardware/irq.h"
#include "hardware/i2c.h"
#include "tusb.h"
#include "bsp/board.h"
#include "i2s_rx.pio.h"
#include "si5351.h"
#include "lcd_driver.h"
#include "class/audio/audio_device.h"

// --- Hardware Pins ---
#define ENC_A_PIN    20
#define ENC_B_PIN    21
#define LED_PIN      25
#define I2C_SDA_PIN  12
#define I2C_SCL_PIN  13
#define I2S_DATA_PIN 2    // DOUT
#define I2S_BCK_PIN  0
#define I2S_WS_PIN   1

// --- State Variables ---
static volatile uint32_t current_hz = 5680000; 
static volatile bool frequency_changed = true;
static bool sentinel_sent = false;

static uint8_t  s_audio_alt      = 0;
static uint32_t s_sample_rate_hz = 48000U;
static uint8_t  s_mute[3]        = {0, 0, 0}; 

// --- DMA & Audio Buffers ---
#define SINGLE_BUFFER_SIZE  768             
#define WORDS_PER_BUF       (SINGLE_BUFFER_SIZE / 4)  
static uint32_t buf_a[WORDS_PER_BUF];
static uint32_t buf_b[WORDS_PER_BUF];
static uint dma_chan_a, dma_chan_b;

// --- ISRs ---
static void __not_in_flash_func(dma_handler)(void) {
    const uint32_t *filled_buf;
    if (dma_channel_get_irq0_status(dma_chan_a)) {
        dma_channel_acknowledge_irq0(dma_chan_a);
        filled_buf = buf_a;
        dma_channel_set_write_addr(dma_chan_a, buf_a, false);
    } else if (dma_channel_get_irq0_status(dma_chan_b)) {
        dma_channel_acknowledge_irq0(dma_chan_b);
        filled_buf = buf_b;
        dma_channel_set_write_addr(dma_chan_b, buf_b, false);
    } else return;
    multicore_fifo_push_timeout_us((uint32_t)(uintptr_t)filled_buf, 0);
}

void encoder_callback(uint gpio, uint32_t events) {
    if (gpio == ENC_A_PIN) {
        if (gpio_get(ENC_B_PIN)) current_hz += 40000;
        else current_hz -= 40000;
        frequency_changed = true;
    }
}

// --- Tasks ---
static void core1_entry(void) {
    multicore_fifo_drain();               
    irq_clear(DMA_IRQ_0);
    dma_channel_set_irq0_enabled(dma_chan_a, true);
    dma_channel_set_irq0_enabled(dma_chan_b, true);
    irq_set_exclusive_handler(DMA_IRQ_0, dma_handler);
    irq_set_enabled(DMA_IRQ_0, true);
    dma_channel_start(dma_chan_a);        
    while (true) { tight_loop_contents(); }
}

static void audio_task(void) {
    uint32_t ptr_val = 0;
    if (multicore_fifo_pop_timeout_us(0, &ptr_val) && ptr_val != 0) {
        uint32_t *src = (uint32_t *)(uintptr_t)ptr_val;
        for (int i = 0; i < WORDS_PER_BUF; i++) src[i] &= 0xFFFFFF00; 
        if (s_audio_alt == 1) tud_audio_write(src, SINGLE_BUFFER_SIZE);
    }
}

void cdc_task(void) {
    if (!tud_cdc_connected()) { sentinel_sent = false; return; }
    if (!sentinel_sent) { 
        tud_cdc_write("SDR ready\n", 10);
        tud_cdc_write_flush();
        sentinel_sent = true; 
    }
}

int main(void) {
    // Replace board_init(); with:
    stdio_init_all();
    tusb_init();

    lcd_init();
    i2c_init(i2c0, 400 * 1000);
    gpio_set_function(I2C_SDA_PIN, GPIO_FUNC_I2C);
    gpio_set_function(I2C_SCL_PIN, GPIO_FUNC_I2C);
    si5351_init(i2c0);

    gpio_init(ENC_A_PIN); gpio_pull_up(ENC_A_PIN);
    gpio_init(ENC_B_PIN); gpio_pull_up(ENC_B_PIN);
    gpio_set_irq_enabled_with_callback(ENC_A_PIN, GPIO_IRQ_EDGE_RISE, true, &encoder_callback);

    PIO pio = pio0;
    uint offset = pio_add_program(pio, &i2s_rx_program);
    // Your pins are: BCK=0, WS=1, DOUT=2. The base pin is 0.
// PIO will automatically assign: base+0=BCK, base+1=WS, base+2=DOUT.
    i2s_rx_program_init(pio, 0, offset, 0);
    dma_chan_a = dma_claim_unused_channel(true);
    dma_chan_b = dma_claim_unused_channel(true);
    
    dma_channel_config c = dma_channel_get_default_config(dma_chan_a);
    channel_config_set_transfer_data_size(&c, DMA_SIZE_32);
    channel_config_set_read_increment(&c, false);
    channel_config_set_write_increment(&c, true);
    channel_config_set_dreq(&c, pio_get_dreq(pio, 0, false));
    dma_channel_configure(dma_chan_a, &c, buf_a, &pio->rxf[0], WORDS_PER_BUF, false);
    
    // ... Repeat for dma_chan_b ...

    multicore_launch_core1(core1_entry);

    while (1) {
        tud_task();    
        cdc_task();    
        audio_task();  

        // Inside while(1) loop in main.c
        gpio_put(LED_PIN, 1);
        sleep_ms(500);
        gpio_put(LED_PIN, 0);
        sleep_ms(500);

        tud_task();
        cdc_task();
        audio_task();

        if (frequency_changed) {
            // Keep the oscillator running at the 4x frequency
            si5351_set_frequency(i2c0, SI5351_CLK0, current_hz, SI5351_INTEGER_APPROX, SI5351_CLK_NONE);
            
            // Calculate the actual tuned frequency for the display (divided by 4)
            uint32_t display_hz = current_hz / 4;
            
            // Format the string (convert Hz to kHz)
            char buf[16];
            snprintf(buf, sizeof(buf), "%4d kHz", (int)(display_hz / 1000));
            
            // Print to the LCD
            lcd_clear();
            lcd_print(buf); 
            frequency_changed = false;
        }
    }
}

// --- Audio Callbacks ---
bool tud_audio_set_itf_cb(uint8_t rhport, tusb_control_request_t const *p_request) { (void)rhport; s_audio_alt = (uint8_t)(p_request->wValue & 0xFF); return true; }
bool tud_audio_set_itf_close_ep_cb(uint8_t rhport, tusb_control_request_t const *p_request) { return true; }
bool tud_audio_get_req_ep_cb(uint8_t rhport, tusb_control_request_t const *p_request) { return false; }
bool tud_audio_set_req_ep_cb(uint8_t rhport, tusb_control_request_t const *p_request, uint8_t *pBuff) { return true; }
bool tud_audio_get_req_entity_cb(uint8_t rhport, tusb_control_request_t const *p_request) { return false; }
bool tud_audio_set_req_entity_cb(uint8_t rhport, tusb_control_request_t const *p_request, uint8_t *pBuff) { return true; }

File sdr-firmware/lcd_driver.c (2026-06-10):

#include "lcd_driver.h"
#include "hardware/gpio.h"

#define RS_PIN 14
#define E_PIN  15
 // fixed verson - fully working driver

// Pins DB0 to DB7
static const uint DB_PINS[] = {3, 4, 5, 6, 7, 8, 9, 10};

static void lcd_pulse_e() {
    gpio_put(E_PIN, 1);
    sleep_us(1); // Enable pulse width >= 300ns
    gpio_put(E_PIN, 0);
    sleep_us(100);
}

static void lcd_write_bus(uint8_t val) {
    for (int i = 0; i < 8; i++) {
        gpio_put(DB_PINS[i], (val >> i) & 1);
    }
}

void lcd_command(uint8_t cmd) {
    gpio_put(RS_PIN, 0); // Command Mode
    lcd_write_bus(cmd);
    lcd_pulse_e();
}

void lcd_init() {
    gpio_init(RS_PIN); gpio_set_dir(RS_PIN, GPIO_OUT);
    gpio_init(E_PIN);  gpio_set_dir(E_PIN, GPIO_OUT);
    for(int i=0; i<8; i++) {
        gpio_init(DB_PINS[i]);
        gpio_set_dir(DB_PINS[i], GPIO_OUT);
    }

    sleep_ms(100);       // Wait >40msec
    lcd_command(0x30);   // Wake up
    sleep_ms(30);
    lcd_command(0x30);   // Wake up #2
    sleep_ms(10);
    lcd_command(0x30);   // Wake up #3
    
    lcd_command(0x38);   // Function set: 8-bit, 1-line [cite: 259]
    lcd_command(0x0C);   // Display ON, Cursor OFF
    lcd_clear();
}

void lcd_clear() {
    lcd_command(0x01);
    sleep_ms(2);
}

void lcd_print(const char* str) {
    gpio_put(RS_PIN, 1); // Data Mode
    while (*str && (str - str < 8)) { // 8 chars max
        lcd_write_bus(*str++);
        lcd_pulse_e();
    }
}

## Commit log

2026-05-21 Added v1 of board; Switch mixer design.
    [SDR-v1-SwitchMixer.kicad_pcb, SDR-v1-SwitchMixer.kicad_sch]
2026-05-21 Rename SDR-v1-SwitchMixer.kicad_pcb to KiCad Designs/Version 1 Switch Mixer/SDR-v1-SwitchMixer.kicad_pcb
    [SDR-v1-SwitchMixer.kicad_pcb]
2026-05-21 File structure fixes
    Fixed broken file structure
    [ENGR254-sdr.kicad_pcb, ENGR254-sdr.kicad_sch, ENGR356-v2.kicad_pcb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]
2026-05-21 Added amp stage simulation
2026-06-01 Initial commit: scaffolded project structure for Pico SDR
2026-06-04 Failed attempt to get UAC1 detection
    [main.c]
2026-06-04 More verbose USB Device descriptors
2026-06-04 FIXED UAC1 AUDIO DEVICE - MAC/LINUX VERIFIED
    [main.c, si5351.c]
2026-06-05 Encoder + USB Audio Works
2026-06-05 Added .py test files; added lcd driver; reverted to working UAC1 code
    [encoder_am_tune_test.py, encoder_si5351_tune_test.py, lcd_driver.c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]
2026-06-06 Attempt to fix kicad files and added schematic pdf to documents folder
2026-06-06 added fix attempt for kicad file
    [ENGR356-v2.kicad_pcb, ENGR356-v2.kicad_sch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]
2026-06-07 FInished Inital Hardware Documentation
    [ENGR356-v2.kicad_pcb, ENGR356-v2.kicad_sch, SDR-v1-SwitchMixer.kicad_pcb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]
2026-06-07 Unified folder names
    [ENGR356-v2.kicad_pcb, ENGR356-v2.kicad_sch, SDR-v1-SwitchMixer.kicad_pcb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]
2026-06-07 Added clean schematic
2026-06-10 Added voltage and clock verification to documentation with photos
2026-06-10 fixed LCD output to match johnson counter, not si5351
    [main.c]
2026-06-10 fixed photo in presentation
    [lcd_driver.c]
2026-06-10 Added design hurdle of having to switch designs at the end of April
2026-06-10 Added in fixed names for voltage analysis
